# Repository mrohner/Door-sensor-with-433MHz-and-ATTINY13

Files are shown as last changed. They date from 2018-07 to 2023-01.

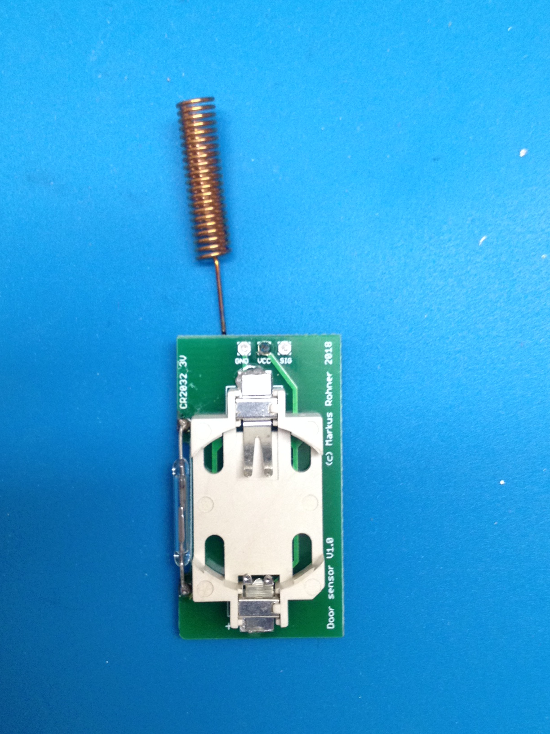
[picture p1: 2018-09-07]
prototype4f.JPG

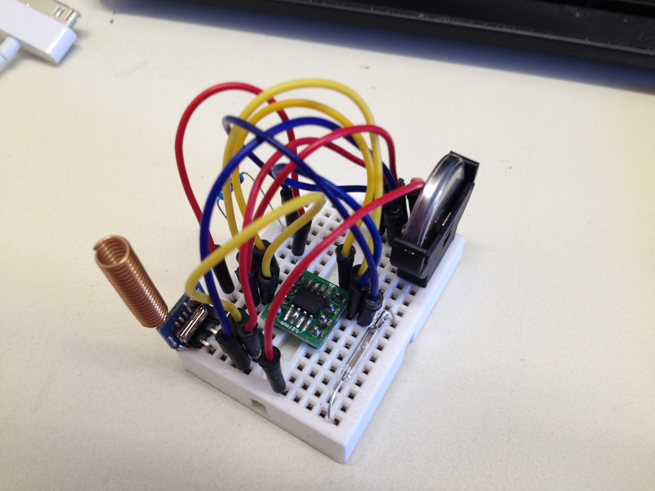
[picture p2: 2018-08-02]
Prototype3.JPG

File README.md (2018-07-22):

# Door-sensor-with-433MHz-and-ATTINY13
Door and Window sensor sends open and close code to home automation system

## Function
This is a little device with a reed switch one one side of the door/window and a magnet on the other side. When the door/window
opens a code will be sent through the 433MHz transciever (I use a Wireless Transmitter Module H34B). When the door/window closes another code will be sent. There is also an optional tampering switch possible. Additionally every 10 minutes a third code is sent. Hence you know when the battery is dead when no more such codes are received.
The sensors work together with https://github.com/mrohner/433MHz-MQTT-Bridge-with-Wemos-D1 in order to relay the door/window status to
MQTT and eventually to Domoticz.

## Design
I used an ATTINY13A and attached a reed switch as well as a 433MHz transciever. All runs off a 3V CR2032 battery. Of course the ATTINY
is asleep most of the time. I attach an Eagle Cad file FYI. The protocol used is understandable by most receivers, see also
https://github.com/sui77/rc-switch and https://github.com/sweetpi/attiny-433mhz-sender
```
/* Format for protocol definitions:
 * {pulselength, Sync bit, "0" bit, "1" bit}
 * 
 * pulselength: pulse length in microseconds, e.g. 350
 * Sync bit: {1, 31} means 1 high pulse and 31 low pulses
 *     (perceived as a 31*pulselength long pulse, total length of sync bit is
 *     32*pulselength microseconds), i.e:
 *      _
 *     | |_______________________________ (don't count the vertical bars)
 * "0" bit: waveform for a data bit of value "0", {1, 3} means 1 high pulse
 *     and 3 low pulses, total length (1+3)*pulselength, i.e:
 *      _
 *     | |___
 * "1" bit: waveform for a data bit of value "1", e.g. {3,1}:
 *      ___
 *     |   |_
 *
 * These are combined to form Tri-State bits when sending or receiving codes.
 */
```
## Library used
You will need this library: https://github.com/NicoHood/PinChangeInterrupt

## Parts used
* PCB board
* ATTINY13A microcontroller SOP-8
* Reed Switch
* 10K Ohm resistor SMD 0805
* Battery holder SMD for CR2032
* Battery CR2032 3V
* 433Mhz transmitter module H34B
* Little housing
* Magnet (I use a furniture door closing magnet)

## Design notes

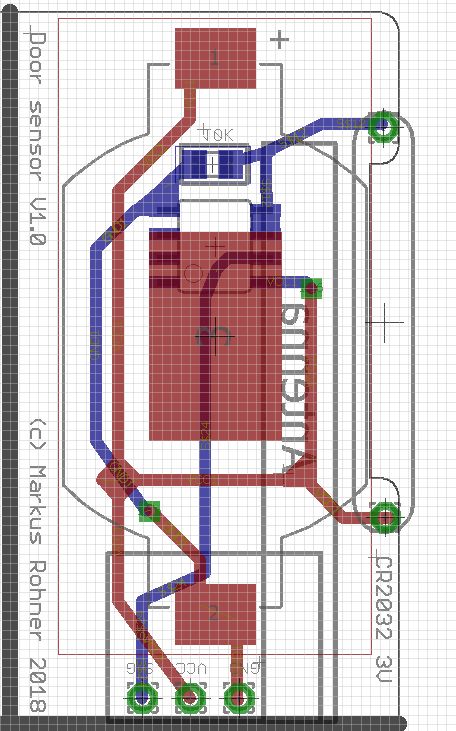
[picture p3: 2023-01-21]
Board_Image.jpg

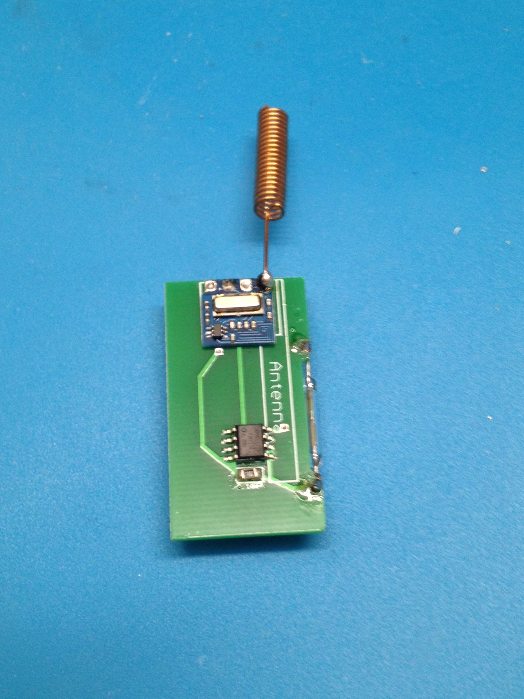
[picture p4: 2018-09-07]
prototype4b.JPG

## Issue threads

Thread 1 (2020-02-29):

circuit diagram needed

shariramani, 2020-02-29:
I am trying to make it. Just wondering how the attiny-13 pins are connected to reed switch and resistance. It will be nice if you can draw a diagram and share.

I looked at brd file and photoes but couldn't understand circuit. I will be handsoldering it on a perforrated board.

evilknivel, 2023-01-21:
@shariramani hi as fare as i understand the Code and the pictures the reed goes to PB0 and PB1 as well. With 10k to ground. Ohn3 PCI waits for the rising and the other PCI waits for them raising signal and fires the respective routine.

mrohner, 2023-01-21:
Hi, Sorry, I do not have a schematic drawing but please see Board_Image.img

evilknivel, 2023-01-21:
@mrohner so first leg from the reed to VCC second leg from the reed to PB0 and PB1 and both via 10k resistor to ground. Right?

shariramani, 2023-01-22:
@evilknivel you can see my schematic here [https://openplatform.xyz/attiny13_low_power_door_sensor.html](https://openplatform.xyz/attiny13_low_power_door_sensor.html)

Reed is between Ground and PB0. Resister is between vcc and PB0.
I used PB1 to connect a LED through a jumper. This is optional. I used it for troubleshooting. You can remove jumper to save battery.

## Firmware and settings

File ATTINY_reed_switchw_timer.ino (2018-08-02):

/*
ATTINY13A Pins
--------------
PB0: reed switch      over 10kOhm to GND
PB1: same reed switch resp. connected to PB0
PB2: 433Mhz sender
PB4: TAMPERing switch over 10kOhm to GND (not used)

Markus Rohner 13.7.2018

 * Format for protocol definitions:
 * {pulselength, Sync bit, "0" bit, "1" bit}
 * 
 * pulselength: pulse length in microseconds, e.g. 350
 * Sync bit: {1, 31} means 1 high pulse and 31 low pulses
 *     (perceived as a 31*pulselength long pulse, total length of sync bit is
 *     32*pulselength microseconds), i.e:
 *      _
 *     | |_______________________________ (don't count the vertical bars)
 * "0" bit: waveform for a data bit of value "0", {1, 3} means 1 high pulse
 *     and 3 low pulses, total length (1+3)*pulselength, i.e:
 *      _
 *     | |___
 * "1" bit: waveform for a data bit of value "1", e.g. {3,1}:
 *      ___
 *     |   |_
 *
 * These are combined to form Tri-State bits when sending or receiving codes.
 */


#include <avr/io.h>
#include <avr/interrupt.h>
#include <util/delay.h>
#include <avr/sleep.h>
#include "PinChangeInterrupt.h"
#define TRANS_PIN PB2
#define INPUT_PIN0 PB0
#define INPUT_PIN1 PB1

volatile byte message = 0;
volatile byte time_counter;
const int SPEED = 330/8; //350 nominal / 8 prescaler (processor runs at 1.2 MHz, uses less power this way)
const byte START = 31;
const byte _SHORT = 1;
const byte _LONG = 3;
// The code you may change per device
const byte OPEN =  0b00000001;//Decimal: 65793  (24Bit) Binary: 000000010000000100000001
const byte CLOSE = 0b00000010;//Decimal: 131586 (24Bit) Binary: 000000100000001000000010
const byte ALIVE = 0b00000011;//Decimal: 197379 (24Bit) Binary: 000000110000001100000011


void setup(){
  // Configure TRANS_PIN as output
  DDRB |= (1 << TRANS_PIN);
  // Set INPUT_PINs as Input
  DDRB &= ~(1 << INPUT_PIN0) | (1 << INPUT_PIN1);
  MCUCR = (1 << SM1);   // define power down sleep mode
  WDTCR |= (1 << WDCE) | (1 << WDE);// Watchdog reset
  WDTCR = (1 << WDE) | (1 << WDP0) | (1 << WDP3); // define prescaler to 8s for WDT interrupt
  // attach the new PinChangeInterrupts and enable event functions 
  attachPinChangeInterrupt(digitalPinToPinChangeInterrupt(INPUT_PIN0), tick, RISING);
  attachPinChangeInterrupt(digitalPinToPinChangeInterrupt(INPUT_PIN1), tock, FALLING);
  enable_PinChange_interrupts ();
}


void loop() {
  // change into sleep mode
  PORTB &= ~(1 << TRANS_PIN); // Set TRANS_PIN low
  ADCSRA &= ~(1<<ADEN);       // Power reduction: disable ADC
  sleep_mode();               // Processor goes to sleep here
  ADCSRA |= (1 << ADEN);      // ADC enable
  disable_PinChange_interrupts ();
  if (message){
    send(message);
    message = 0;
 //   _delay_ms(50);
  }
  if (time_counter > 60) {// ca. 10 minutes
    send(ALIVE);
    time_counter = 0;
  }
  enable_PinChange_interrupts ();  
}

void tick(void) {
  message = OPEN;
}

void tock(void) {
  message = CLOSE;
}


void enable_PinChange_interrupts () {
  WDTCR |= (1 << WDTIE);// Enable watchdog timer interrupts
  enablePinChangeInterrupt(digitalPinToPinChangeInterrupt(INPUT_PIN0));
  enablePinChangeInterrupt(digitalPinToPinChangeInterrupt(INPUT_PIN1));
}


void disable_PinChange_interrupts () {
  WDTCR &= ~(1 << WDTIE);   // Disable WDT interrupts
  disablePinChangeInterrupt(digitalPinToPinChangeInterrupt(INPUT_PIN0));
  disablePinChangeInterrupt(digitalPinToPinChangeInterrupt(INPUT_PIN1));
}


void send(byte id){
  for(byte i=0;i<15;i++) {// Send message 15-30 times 
    //Send Start sequence
    digitalWrite(1);
    _delay_us((SPEED*_SHORT));
    digitalWrite(0);
    _delay_us((SPEED*START));
    //Send code
    for(byte x=0;x<3;x++) {//  send 3 times same 8 bits = 24 bit code
      for (unsigned int y = 8; y-- > 0;){ 
        if(bitRead(id,y)) sendPulse1();
        else sendPulse0();
      }
    }
  }
}


void sendPulse0() {
  digitalWrite(1);
  _delay_us((SPEED*_SHORT));
  digitalWrite(0);
  _delay_us((SPEED*_LONG));
}


void sendPulse1() {
  digitalWrite(1);
  _delay_us((SPEED*_LONG));
  digitalWrite(0);
  _delay_us((SPEED*_SHORT));
}


void digitalWrite(bool val){
  if(val)PORTB |= (1 << TRANS_PIN);
  else PORTB &= ~(1 << TRANS_PIN);
}


ISR(WDT_vect) {
  time_counter++;
}
